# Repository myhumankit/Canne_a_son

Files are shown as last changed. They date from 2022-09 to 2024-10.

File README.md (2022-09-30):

# Canne_a_son

Prototype de canne blanche électronique pour détecter des obstacles. 

Ce projet est expliqué en détail sur le wikilab de My Human Kit : https://wikilab.myhumankit.org/index.php?title=Projets:Canne_a_son_V2

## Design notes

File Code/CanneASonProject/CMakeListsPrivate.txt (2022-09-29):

# !!! WARNING !!! AUTO-GENERATED FILE, PLEASE DO NOT MODIFY IT AND USE
# https://docs.platformio.org/page/projectconf/section_env_build.html#build-flags
#
# If you need to override existing CMake configuration or add extra,
# please create `CMakeListsUser.txt` in the root of project.
# The `CMakeListsUser.txt` will not be overwritten by PlatformIO.

set(CMAKE_CONFIGURATION_TYPES "m5stack-atom" CACHE STRING "Build Types reflect PlatformIO Environments" FORCE)

# Convert "Home Directory" that may contain unescaped backslashes on Windows
file(TO_CMAKE_PATH $ENV{HOMEDRIVE}$ENV{HOMEPATH} ENV_HOME_PATH)

SET(CMAKE_C_COMPILER "${ENV_HOME_PATH}/.platformio/packages/toolchain-xtensa-esp32/bin/xtensa-esp32-elf-gcc.exe")
SET(CMAKE_CXX_COMPILER "${ENV_HOME_PATH}/.platformio/packages/toolchain-xtensa-esp32/bin/xtensa-esp32-elf-g++.exe")
SET(CMAKE_CXX_FLAGS "-mlongcalls -Wno-frame-address -std=gnu++11 -fexceptions -fno-rtti -ffunction-sections -fdata-sections -Wno-error=unused-function -Wno-error=unused-variable -Wno-error=deprecated-declarations -Wno-unused-parameter -Wno-sign-compare -ggdb -Os -freorder-blocks -Wwrite-strings -fstack-protector -fstrict-volatile-bitfields -Wno-error=unused-but-set-variable -fno-jump-tables -fno-tree-switch-conversion -MMD")
SET(CMAKE_C_FLAGS "-mlongcalls -Wno-frame-address -std=gnu99 -Wno-old-style-declaration -ffunction-sections -fdata-sections -Wno-error=unused-function -Wno-error=unused-variable -Wno-error=deprecated-declarations -Wno-unused-parameter -Wno-sign-compare -ggdb -Os -freorder-blocks -Wwrite-strings -fstack-protector -fstrict-volatile-bitfields -Wno-error=unused-but-set-variable -fno-jump-tables -fno-tree-switch-conversion -MMD")

SET(CMAKE_C_STANDARD 99)
set(CMAKE_CXX_STANDARD 11)

if (CMAKE_BUILD_TYPE MATCHES "m5stack-atom")
    add_definitions(-DPLATFORMIO=60002)
    add_definitions(-DARDUINO_M5Stack_ATOM)
    add_definitions(-DHAVE_CONFIG_H)
    add_definitions(-DMBEDTLS_CONFIG_FILE=\"mbedtls/esp_config.h\")
    add_definitions(-DUNITY_INCLUDE_CONFIG_H)
    add_definitions(-DWITH_POSIX)
    add_definitions(-D_GNU_SOURCE)
    add_definitions(-DIDF_VER=\"v4.4.1-1-gb8050b365e\")
    add_definitions(-DESP_PLATFORM)
    add_definitions(-D_POSIX_READER_WRITER_LOCKS)
    add_definitions(-DARDUINO_ARCH_ESP32)
    add_definitions(-DESP32)
    add_definitions(-DF_CPU=240000000L)
    add_definitions(-DARDUINO=10812)
    add_definitions(-DARDUINO_VARIANT=\"m5stack_atom\")
    add_definitions(-DARDUINO_BOARD=\"M5Stack-ATOM\")
    add_definitions(-DARDUINO_PARTITION_default)

    include_directories("${CMAKE_CURRENT_LIST_DIR}/include")
    include_directories("${CMAKE_CURRENT_LIST_DIR}/src")
    include_directories("${CMAKE_CURRENT_LIST_DIR}/lib/SmartsonicCH201/src")
    include_directories("${CMAKE_CURRENT_LIST_DIR}/.pio/libdeps/m5stack-atom/TFMPI2C/src")
    include_directories("${CMAKE_CURRENT_LIST_DIR}/.pio/libdeps/m5stack-atom/M5Atom/src")
    include_directories("${ENV_HOME_PATH}/.platformio/packages/framework-arduinoespressif32/libraries/Wire/src")
    include_directories("${CMAKE_CURRENT_LIST_DIR}/.pio/libdeps/m5stack-atom/FastLED/src")
    include_directories("${ENV_HOME_PATH}/.platformio/packages/framework-arduinoespressif32/libraries/SPI/src")
    include_directories("${ENV_HOME_PATH}/.platformio/packages/framework-arduinoespressif32/tools/sdk/esp32/include/config")
    include_directories("${ENV_HOME_PATH}/.platformio/packages/framework-arduinoespressif32/tools/sdk/esp32/include/newlib/platform_include")
    include_directories("${ENV_HOME_PATH}/.platformio/packages/framework-arduinoespressif32/tools/sdk/esp32/include/freertos/include")
    include_directories("${ENV_HOME_PATH}/.platformio/packages/framework-arduinoespressif32/tools/sdk/esp32/include/freertos/include/esp_additions/freertos")
    include_directories("${ENV_HOME_PATH}/.platformio/packages/framework-arduinoespressif32/tools/sdk/esp32/include/freertos/port/xtensa/include")
    include_directories("${ENV_HOME_PATH}/.platformio/packages/framework-arduinoespressif32/tools/sdk/esp32/include/freertos/include/esp_additions")
    include_directories("${ENV_HOME_PATH}/.platformio/packages/framework-arduinoespressif32/tools/sdk/esp32/include/esp_hw_support/include")
    include_directories("${ENV_HOME_PATH}/.platformio/packages/framework-arduinoespressif32/tools/sdk/esp32/include/esp_hw_support/include/soc")
    include_directories("${ENV_HOME_PATH}/.platformio/packages/framework-arduinoespressif32/tools/sdk/esp32/include/esp_hw_support/include/soc/esp32")
    include_directories("${ENV_HOME_PATH}/.platformio/packages/framework-arduinoespressif32/tools/sdk/esp32/include/esp_hw_support/port/esp32")
    include_directories("${ENV_HOME_PATH}/.platformio/packages/framework-arduinoespressif32/tools/sdk/esp32/include/esp_hw_support/port/esp32/private_include")
    include_directories("${ENV_HOME_PATH}/.platformio/packages/framework-arduinoespressif32/tools/sdk/esp32/include/heap/include")
    include_directories("${ENV_HOME_PATH}/.platformio/packages/framework-arduinoespressif32/tools/sdk/esp32/include/log/include")
    include_directories("${ENV_HOME_PATH}/.platformio/packages/framework-arduinoespressif32/tools/sdk/esp32/include/lwip/include/apps")
    include_directories("${ENV_HOME_PATH}/.platformio/packages/framework-arduinoespressif32/tools/sdk/esp32/include/lwip/include/apps/sntp")
    include_directories("${ENV_HOME_PATH}/.platformio/packages/framework-arduinoespressif32/tools/sdk/esp32/include/lwip/lwip/src/include")
    include_directories("${ENV_HOME_PATH}/.platformio/packages/framework-arduinoespressif32/tools/sdk/esp32/include/lwip/port/esp32/include")
    include_directories("${ENV_HOME_PATH}/.platformio/packages/framework-arduinoespressif32/tools/sdk/esp32/include/lwip/port/esp32/include/arch")
    include_directories("${ENV_HOME_PATH}/.platformio/packages/framework-arduinoespressif32/tools/sdk/esp32/include/soc/include")
    include_directories("${ENV_HOME_PATH}/.platformio/packages/framework-arduinoespressif32/tools/sdk/esp32/include/soc/esp32")
    include_directories("${ENV_HOME_PATH}/.platformio/packages/framework-arduinoespressif32/tools/sdk/esp32/include/soc/esp32/include")
    include_directories("${ENV_HOME_PATH}/.platformio/packages/framework-arduinoespressif32/tools/sdk/esp32/include/hal/esp32/include")
    include_directories("${ENV_HOME_PATH}/.platformio/packages/framework-arduinoespressif32/tools/sdk/esp32/include/hal/include")
    include_directories("${ENV_HOME_PATH}/.platformio/packages/framework-arduinoespressif32/tools/sdk/esp32/include/hal/platform_port/include")
    include_directories("${ENV_HOME_PATH}/.platformio/packages/framework-arduinoespressif32/tools/sdk/esp32/include/esp_rom/include")
    include_directories("${ENV_HOME_PATH}/.platformio/packages/framework-arduinoespressif32/tools/sdk/esp32/include/esp_rom/include/esp32")
    include_directories("${ENV_HOME_PATH}/.platformio/packages/framework-arduinoespressif32/tools/sdk/esp32/include/esp_rom/esp32")
    include_directories("${ENV_HOME_PATH}/.platformio/packages/framework-arduinoespressif32/tools/sdk/esp32/include/esp_common/include")
    include_directories("${ENV_HOME_PATH}/.platformio/packages/framework-arduinoespressif32/tools/sdk/esp32/include/esp_system/include")
    include_directories("${ENV_HOME_PATH}/.platformio/packages/framework-arduinoespressif32/tools/sdk/esp32/include/esp_system/port/soc")
    include_directories("${ENV_HOME_PATH}/.platformio/packages/framework-arduinoespressif32/tools/sdk/esp32/include/esp_system/port/public_compat")
    include_directories("${ENV_HOME_PATH}/.platformio/packages/framework-arduinoespressif32/tools/sdk/esp32/include/esp32/include")
    include_directories("${ENV_HOME_PATH}/.platformio/packages/framework-arduinoespressif32/tools/sdk/esp32/include/xtensa/include")
    include_directories("${ENV_HOME_PATH}/.platformio/packages/framework-arduinoespressif32/tools/sdk/esp32/include/xtensa/esp32/include")
    include_directories("${ENV_HOME_PATH}/.platformio/packages/framework-arduinoespressif32/tools/sdk/esp32/include/driver/include")
    include_directories("${ENV_HOME_PATH}/.platformio/packages/framework-arduinoespressif32/tools/sdk/esp32/include/driver/esp32/include")
    include_directories("${ENV_HOME_PATH}/.platformio/packages/framework-arduinoespressif32/tools/sdk/esp32/include/esp_pm/include")
    include_directories("${ENV_HOME_PATH}/.platformio/packages/framework-arduinoespressif32/tools/sdk/esp32/include/esp_ringbuf/include")
    include_directories("${ENV_HOME_PATH}/.platformio/packages/framework-arduinoespressif32/tools/sdk/esp32/include/efuse/include")
    include_directories("${ENV_HOME_PATH}/.platformio/packages/framework-arduinoespressif32/tools/sdk/esp32/include/efuse/esp32/include")
    include_directories("${ENV_HOME_PATH}/.platformio/packages/framework-arduinoespressif32/tools/sdk/esp32/include/vfs/include")
    include_directories("${ENV_HOME_PATH}/.platformio/packages/framework-arduinoespressif32/tools/sdk/esp32/include/esp_wifi/include")
    include_directories("${ENV_HOME_PATH}/.platformio/packages/framework-arduinoespressif32/tools/sdk/esp32/include/esp_event/include")
    include_directories("${ENV_HOME_PATH}/.platformio/packages/framework-arduinoespressif32/tools/sdk/esp32/include/esp_netif/include")
    include_directories("${ENV_HOME_PATH}/.platformio/packages/framework-arduinoespressif32/tools/sdk/esp32/include/esp_eth/include")
    include_directories("${ENV_HOME_PATH}/.platformio/packages/framework-arduinoespressif32/tools/sdk/esp32/include/tcpip_adapter/include")
    include_directories("${ENV_HOME_PATH}/.platformio/packages/framework-arduinoespressif32/tools/sdk/esp32/include/esp_phy/include")
    include_directories("${ENV_HOME_PATH}/.platformio/packages/framework-arduinoespressif32/tools/sdk/esp32/include/esp_phy/esp32/include")
    include_directories("${ENV_HOME_PATH}/.platformio/packages/framework-arduinoespressif32/tools/sdk/esp32/include/esp_ipc/include")
    include_directories("${ENV_HOME_PATH}/.platformio/packages/framework-arduinoespressif32/tools/sdk/esp32/include/app_trace/include")
    include_directories("${ENV_HOME_PATH}/.platformio/packages/framework-arduinoespressif32/tools/sdk/esp32/include/esp_timer/include")
    include_directories("${ENV_HOME_PATH}/.platformio/packages/framework-arduinoespressif32/tools/sdk/esp32/include/mbedtls/port/include")
    include_directories("${ENV_HOME_PATH}/.platformio/packages/framework-arduinoespressif32/tools/sdk/esp32/include/mbedtls/mbedtls/include")
    include_directories("${ENV_HOME_PATH}/.platformio/packages/framework-arduinoespressif32/tools/sdk/esp32/include/mbedtls/esp_crt_bundle/include")
    include_directories("${ENV_HOME_PATH}/.platformio/packages/framework-arduinoespressif32/tools/sdk/esp32/include/app_update/include")
    include_directories("${ENV_HOME_PATH}/.platformio/packages/framework-arduinoespressif32/tools/sdk/esp32/include/spi_flash/include")
    include_directories("${ENV_HOME_PATH}/.platformio/packages/framework-arduinoespressif32/tools/sdk/esp32/include/bootloader_support/include")
    include_directories("${ENV_HOME_PATH}/.platformio/packages/framework-arduinoespressif32/tools/sdk/esp32/include/nvs_flash/include")
    include_directories("${ENV_HOME_PATH}/.platformio/packages/framework-arduinoespressif32/tools/sdk/esp32/include/pthread/include")
    include_directories("${ENV_HOME_PATH}/.platformio/packages/framework-arduinoespressif32/tools/sdk/esp32/include/esp_gdbstub/include")
    include_directories("${ENV_HOME_PATH}/.platformio/packages/framework-arduinoespressif32/tools/sdk/esp32/include/esp_gdbstub/xtensa")
    include_directories("${ENV_HOME_PATH}/.platformio/packages/framework-arduinoespressif32/tools/sdk/esp32/include/esp_gdbstub/esp32")
    include_directories("${ENV_HOME_PATH}/.platformio/packages/framework-arduinoespressif32/tools/sdk/esp32/include/espcoredump/include")
    include_directories("${ENV_HOME_PATH}/.platformio/packages/framework-arduinoespressif32/tools/sdk/esp32/include/espcoredump/include/port/xtensa")
    include_directories("${ENV_HOME_PATH}/.platformio/packages/framework-arduinoespressif32/tools/sdk/esp32/include/wpa_supplicant/include")
    include_directories("${ENV_HOME_PATH}/.platformio/packages/framework-arduinoespressif32/tools/sdk/esp32/include/wpa_supplicant/port/include")
    include_directories("${ENV_HOME_PATH}/.platformio/packages/framework-arduinoespressif32/tools/sdk/esp32/include/wpa_supplicant/esp_supplicant/include")
    include_directories("${ENV_HOME_PATH}/.platformio/packages/framework-arduinoespressif32/tools/sdk/esp32/include/ieee802154/include")
    include_directories("${ENV_HOME_PATH}/.platformio/packages/framework-arduinoespressif32/tools/sdk/esp32/include/console")
    include_directories("${ENV_HOME_PATH}/.platformio/packages/framework-arduinoespressif32/tools/sdk/esp32/include/asio/asio/asio/include")
    include_directories("${ENV_HOME_PATH}/.platformio/packages/framework-arduinoespressif32/tools/sdk/esp32/include/asio/port/include")
    include_directories("${ENV_HOME_PATH}/.platformio/packages/framework-arduinoespressif32/tools/sdk/esp32/include/bt/common/osi/include")
    include_directories("${ENV_HOME_PATH}/.platformio/packages/framework-arduinoespressif32/tools/sdk/esp32/include/bt/include/esp32/include")
    include_directories("${ENV_HOME_PATH}/.platformio/packages/framework-arduinoespressif32/tools/sdk/esp32/include/bt/common/api/include/api")
    include_directories("${ENV_HOME_PATH}/.platformio/packages/framework-arduinoespressif32/tools/sdk/esp32/include/bt/common/btc/profile/esp/blufi/include")
    include_directories("${ENV_HOME_PATH}/.platformio/packages/framework-arduinoespressif32/tools/sdk/esp32/include/bt/common/btc/profile/esp/include")
    include_directories("${ENV_HOME_PATH}/.platformio/packages/framework-arduinoespressif32/tools/sdk/esp32/include/bt/host/bluedroid/api/include/api")
    include_directories("${ENV_HOME_PATH}/.platformio/packages/framework-arduinoespressif32/tools/sdk/esp32/include/cbor/port/include")
    include_directories("${ENV_HOME_PATH}/.platformio/packages/framework-arduinoespressif32/tools/sdk/esp32/include/unity/include")
    include_directories("${ENV_HOME_PATH}/.platformio/packages/framework-arduinoespressif32/tools/sdk/esp32/include/unity/unity/src")
    include_directories("${ENV_HOME_PATH}/.platformio/packages/framework-arduinoespressif32/tools/sdk/esp32/include/cmock/CMock/src")
    include_directories("${ENV_HOME_PATH}/.platformio/packages/framework-arduinoespressif32/tools/sdk/esp32/include/coap/port/include")
    include_directories("${ENV_HOME_PATH}/.platformio/packages/framework-arduinoespressif32/tools/sdk/esp32/include/coap/libcoap/include")
    include_directories("${ENV_HOME_PATH}/.platformio/packages/framework-arduinoespressif32/tools/sdk/esp32/include/nghttp/port/include")
    include_directories("${ENV_HOME_PATH}/.platformio/packages/framework-arduinoespressif32/tools/sdk/esp32/include/nghttp/nghttp2/lib/includes")
    include_directories("${ENV_HOME_PATH}/.platformio/packages/framework-arduinoespressif32/tools/sdk/esp32/include/esp-tls")
    include_directories("${ENV_HOME_PATH}/.platformio/packages/framework-arduinoespressif32/tools/sdk/esp32/include/esp-tls/esp-tls-crypto")
    include_directories("${ENV_HOME_PATH}/.platformio/packages/framework-arduinoespressif32/tools/sdk/esp32/include/esp_adc_cal/include")
    include_directories("${ENV_HOME_PATH}/.platformio/packages/framework-arduinoespressif32/tools/sdk/esp32/include/esp_hid/include")
    include_directories("${ENV_HOME_PATH}/.platformio/packages/framework-arduinoespressif32/tools/sdk/esp32/include/tcp_transport/include")
    include_directories("${ENV_HOME_PATH}/.platformio/packages/framework-arduinoespressif32/tools/sdk/esp32/include/esp_http_client/include")
    include_directories("${ENV_HOME_PATH}/.platformio/packages/framework-arduinoespressif32/tools/sdk/esp32/include/esp_http_server/include")
    include_directories("${ENV_HOME_PATH}/.platformio/packages/framework-arduinoespressif32/tools/sdk/esp32/include/esp_https_ota/include")
    include_directories("${ENV_HOME_PATH}/.platformio/packages/framework-arduinoespressif32/tools/sdk/esp32/include/esp_lcd/include")
    include_directories("${ENV_HOME_PATH}/.platformio/packages/framework-arduinoespressif32/tools/sdk/esp32/include/esp_lcd/interface")
    include_directories("${ENV_HOME_PATH}/.platformio/packages/framework-arduinoespressif32/tools/sdk/esp32/include/protobuf-c/protobuf-c")
    include_directories("${ENV_HOME_PATH}/.platformio/packages/framework-arduinoespressif32/tools/sdk/esp32/include/protocomm/include/common")
    include_directories("${ENV_HOME_PATH}/.platformio/packages/framework-arduinoespressif32/tools/sdk/esp32/include/protocomm/include/security")
    include_directories("${ENV_HOME_PATH}/.platformio/packages/framework-arduinoespressif32/tools/sdk/esp32/include/protocomm/include/transports")
    include_directories("${ENV_HOME_PATH}/.platformio/packages/framework-arduinoespressif32/tools/sdk/esp32/include/mdns/include")
    include_directories("${ENV_HOME_PATH}/.platformio/packages/framework-arduinoespressif32/tools/sdk/esp32/include/esp_local_ctrl/include")
    include_directories("${ENV_HOME_PATH}/.platformio/packages/framework-arduinoespressif32/tools/sdk/esp32/include/sdmmc/include")
    include_directories("${ENV_HOME_PATH}/.platformio/packages/framework-arduinoespressif32/tools/sdk/esp32/include/esp_serial_slave_link/include")
    include_directories("${ENV_HOME_PATH}/.platformio/packages/framework-arduinoespressif32/tools/sdk/esp32/include/esp_websocket_client/include")
    include_directories("${ENV_HOME_PATH}/.platformio/packages/framework-arduinoespressif32/tools/sdk/esp32/include/expat/expat/expat/lib")
    include_directories("${ENV_HOME_PATH}/.platformio/packages/framework-arduinoespressif32/tools/sdk/esp32/include/expat/port/include")
    include_directories("${ENV_HOME_PATH}/.platformio/packages/framework-arduinoespressif32/tools/sdk/esp32/include/wear_levelling/include")
    include_directories("${ENV_HOME_PATH}/.platformio/packages/framework-arduinoespressif32/tools/sdk/esp32/include/fatfs/diskio")
    include_directories("${ENV_HOME_PATH}/.platformio/packages/framework-arduinoespressif32/tools/sdk/esp32/include/fatfs/vfs")
    include_directories("${ENV_HOME_PATH}/.platformio/packages/framework-arduinoespressif32/tools/sdk/esp32/include/fatfs/src")
    include_directories("${ENV_HOME_PATH}/.platformio/packages/framework-arduinoespressif32/tools/sdk/esp32/include/freemodbus/common/include")
    include_directories("${ENV_HOME_PATH}/.platformio/packages/framework-arduinoespressif32/tools/sdk/esp32/include/idf_test/include")
    include_directories("${ENV_HOME_PATH}/.platformio/packages/framework-arduinoespressif32/tools/sdk/esp32/include/idf_test/include/esp32")
    include_directories("${ENV_HOME_PATH}/.platformio/packages/framework-arduinoespressif32/tools/sdk/esp32/include/jsmn/include")
    include_directories("${ENV_HOME_PATH}/.platformio/packages/framework-arduinoespressif32/tools/sdk/esp32/include/json/cJSON")
    include_directories("${ENV_HOME_PATH}/.platformio/packages/framework-arduinoespressif32/tools/sdk/esp32/include/libsodium/libsodium/src/libsodium/include")
    include_directories("${ENV_HOME_PATH}/.platformio/packages/framework-arduinoespressif32/tools/sdk/esp32/include/libsodium/port_include")
    include_directories("${ENV_HOME_PATH}/.platformio/packages/framework-arduinoespressif32/tools/sdk/esp32/include/mqtt/esp-mqtt/include")
    include_directories("${ENV_HOME_PATH}/.platformio/packages/framework-arduinoespressif32/tools/sdk/esp32/include/openssl/include")
    include_directories("${ENV_HOME_PATH}/.platformio/packages/framework-arduinoespressif32/tools/sdk/esp32/include/perfmon/include")
    include_directories("${ENV_HOME_PATH}/.platformio/packages/framework-arduinoespressif32/tools/sdk/esp32/include/spiffs/include")
    include_directories("${ENV_HOME_PATH}/.platformio/packages/framework-arduinoespressif32/tools/sdk/esp32/include/ulp/include")
    include_directories("${ENV_HOME_PATH}/.platformio/packages/framework-arduinoespressif32/tools/sdk/esp32/include/wifi_provisioning/include")
    include_directories("${ENV_HOME_PATH}/.platformio/packages/framework-arduinoespressif32/tools/sdk/esp32/include/button/button/include")
    include_directories("${ENV_HOME_PATH}/.platformio/packages/framework-arduinoespressif32/tools/sdk/esp32/include/rmaker_common/include")
    include_directories("${ENV_HOME_PATH}/.platformio/packages/framework-arduinoespressif32/tools/sdk/esp32/include/json_parser/upstream/include")
    include_directories("${ENV_HOME_PATH}/.platformio/packages/framework-arduinoespressif32/tools/sdk/esp32/include/json_parser/upstream")
    include_directories("${ENV_HOME_PATH}/.platformio/packages/framework-arduinoespressif32/tools/sdk/esp32/include/json_generator/upstream")
    include_directories("${ENV_HOME_PATH}/.platformio/packages/framework-arduinoespressif32/tools/sdk/esp32/include/esp_schedule/include")
    include_directories("${ENV_HOME_PATH}/.platformio/packages/framework-arduinoespressif32/tools/sdk/esp32/include/esp_rainmaker/include")
    include_directories("${ENV_HOME_PATH}/.platformio/packages/framework-arduinoespressif32/tools/sdk/esp32/include/qrcode/include")
    include_directories("${ENV_HOME_PATH}/.platformio/packages/framework-arduinoespressif32/tools/sdk/esp32/include/ws2812_led")
    include_directories("${ENV_HOME_PATH}/.platformio/packages/framework-arduinoespressif32/tools/sdk/esp32/include/esp-dsp/modules/dotprod/include")
    include_directories("${ENV_HOME_PATH}/.platformio/packages/framework-arduinoespressif32/tools/sdk/esp32/include/esp-dsp/modules/support/include")
    include_directories("${ENV_HOME_PATH}/.platformio/packages/framework-arduinoespressif32/tools/sdk/esp32/include/esp-dsp/modules/windows/include")
    include_directories("${ENV_HOME_PATH}/.platformio/packages/framework-arduinoespressif32/tools/sdk/esp32/include/esp-dsp/modules/windows/hann/include")
    include_directories("${ENV_HOME_PATH}/.platformio/packages/framework-arduinoespressif32/tools/sdk/esp32/include/esp-dsp/modules/windows/blackman/include")
    include_directories("${ENV_HOME_PATH}/.platformio/packages/framework-arduinoespressif32/tools/sdk/esp32/include/esp-dsp/modules/windows/blackman_harris/include")
    include_directories("${ENV_HOME_PATH}/.platformio/packages/framework-arduinoespressif32/tools/sdk/esp32/include/esp-dsp/modules/windows/blackman_nuttall/include")
    include_directories("${ENV_HOME_PATH}/.platformio/packages/framework-arduinoespressif32/tools/sdk/esp32/include/esp-dsp/modules/windows/nuttall/include")
    include_directories("${ENV_HOME_PATH}/.platformio/packages/framework-arduinoespressif32/tools/sdk/esp32/include/esp-dsp/modules/windows/flat_top/include")
    include_directories("${ENV_HOME_PATH}/.platformio/packages/framework-arduinoespressif32/tools/sdk/esp32/include/esp-dsp/modules/iir/include")
    include_directories("${ENV_HOME_PATH}/.platformio/packages/framework-arduinoespressif32/tools/sdk/esp32/include/esp-dsp/modules/fir/include")
    include_directories("${ENV_HOME_PATH}/.platformio/packages/framework-arduinoespressif32/tools/sdk/esp32/include/esp-dsp/modules/math/include")
    include_directories("${ENV_HOME_PATH}/.platformio/packages/framework-arduinoespressif32/tools/sdk/esp32/include/esp-dsp/modules/math/add/include")
    include_directories("${ENV_HOME_PATH}/.platformio/packages/framework-arduinoespressif32/tools/sdk/esp32/include/esp-dsp/modules/math/sub/include")
    include_directories("${ENV_HOME_PATH}/.platformio/packages/framework-arduinoespressif32/tools/sdk/esp32/include/esp-dsp/modules/math/mul/include")
    include_directories("${ENV_HOME_PATH}/.platformio/packages/framework-arduinoespressif32/tools/sdk/esp32/include/esp-dsp/modules/math/addc/include")
    include_directories("${ENV_HOME_PATH}/.platformio/packages/framework-arduinoespressif32/tools/sdk/esp32/include/esp-dsp/modules/math/mulc/include")
    include_directories("${ENV_HOME_PATH}/.platformio/packages/framework-arduinoespressif32/tools/sdk/esp32/include/esp-dsp/modules/math/sqrt/include")
    include_directories("${ENV_HOME_PATH}/.platformio/packages/framework-arduinoespressif32/tools/sdk/esp32/include/esp-dsp/modules/matrix/include")
    include_directories("${ENV_HOME_PATH}/.platformio/packages/framework-arduinoespressif32/tools/sdk/esp32/include/esp-dsp/modules/fft/include")
    include_directories("${ENV_HOME_PATH}/.platformio/packages/framework-arduinoespressif32/tools/sdk/esp32/include/esp-dsp/modules/dct/include")
    include_directories("${ENV_HOME_PATH}/.platformio/packages/framework-arduinoespressif32/tools/sdk/esp32/include/esp-dsp/modules/conv/include")
    include_directories("${ENV_HOME_PATH}/.platformio/packages/framework-arduinoespressif32/tools/sdk/esp32/include/esp-dsp/modules/common/include")
    include_directories("${ENV_HOME_PATH}/.platformio/packages/framework-arduinoespressif32/tools/sdk/esp32/include/esp-dsp/modules/kalman/ekf/include")
    include_directories("${ENV_HOME_PATH}/.platformio/packages/framework-arduinoespressif32/tools/sdk/esp32/include/esp-dsp/modules/kalman/ekf_imu13states/include")
    include_directories("${ENV_HOME_PATH}/.platformio/packages/framework-arduinoespressif32/tools/sdk/esp32/include/esp_littlefs/src")
    include_directories("${ENV_HOME_PATH}/.platformio/packages/framework-arduinoespressif32/tools/sdk/esp32/include/esp_littlefs/include")
    include_directories("${ENV_HOME_PATH}/.platformio/packages/framework-arduinoespressif32/tools/sdk/esp32/include/esp-dl/include")
    include_directories("${ENV_HOME_PATH}/.platformio/packages/framework-arduinoespressif32/tools/sdk/esp32/include/esp-dl/include/tool")
    include_directories("${ENV_HOME_PATH}/.platformio/packages/framework-arduinoespressif32/tools/sdk/esp32/include/esp-dl/include/typedef")
    include_directories("${ENV_HOME_PATH}/.platformio/packages/framework-arduinoespressif32/tools/sdk/esp32/include/esp-dl/include/image")
    include_directories("${ENV_HOME_PATH}/.platformio/packages/framework-arduinoespressif32/tools/sdk/esp32/include/esp-dl/include/math")
    include_directories("${ENV_HOME_PATH}/.platformio/packages/framework-arduinoespressif32/tools/sdk/esp32/include/esp-dl/include/nn")
    include_directories("${ENV_HOME_PATH}/.platformio/packages/framework-arduinoespressif32/tools/sdk/esp32/include/esp-dl/include/layer")
    include_directories("${ENV_HOME_PATH}/.platformio/packages/framework-arduinoespressif32/tools/sdk/esp32/include/esp-dl/include/detect")
    include_directories("${ENV_HOME_PATH}/.platformio/packages/framework-arduinoespressif32/tools/sdk/esp32/include/esp-dl/include/model_zoo")
    include_directories("${ENV_HOME_PATH}/.platformio/packages/framework-arduinoespressif32/tools/sdk/esp32/include/esp-sr/esp-tts/esp_tts_chinese/include")
    include_directories("${ENV_HOME_PATH}/.platformio/packages/framework-arduinoespressif32/tools/sdk/esp32/include/esp-sr/include/esp32")
    include_directories("${ENV_HOME_PATH}/.platformio/packages/framework-arduinoespressif32/tools/sdk/esp32/include/esp32-camera/driver/include")
    include_directories("${ENV_HOME_PATH}/.platformio/packages/framework-arduinoespressif32/tools/sdk/esp32/include/esp32-camera/conversions/include")
    include_directories("${ENV_HOME_PATH}/.platformio/packages/framework-arduinoespressif32/tools/sdk/esp32/include/fb_gfx/include")
    include_directories("${ENV_HOME_PATH}/.platformio/packages/framework-arduinoespressif32/tools/sdk/esp32/qspi_qspi/include")
    include_directories("${ENV_HOME_PATH}/.platformio/packages/framework-arduinoespressif32/cores/esp32")
    include_directories("${ENV_HOME_PATH}/.platformio/packages/framework-arduinoespressif32/variants/m5stack_atom")
    include_directories("${ENV_HOME_PATH}/.platformio/packages/framework-arduinoespressif32/libraries/ArduinoOTA/src")
    include_directories("${ENV_HOME_PATH}/.platformio/packages/framework-arduinoespressif32/libraries/AsyncUDP/src")
    include_directories("${ENV_HOME_PATH}/.platformio/packages/framework-arduinoespressif32/libraries/BLE/src")
    include_directories("${ENV_HOME_PATH}/.platformio/packages/framework-arduinoespressif32/libraries/BluetoothSerial/src")
    include_directories("${ENV_HOME_PATH}/.platformio/packages/framework-arduinoespressif32/libraries/DNSServer/src")
    include_directories("${ENV_HOME_PATH}/.platformio/packages/framework-arduinoespressif32/libraries/EEPROM/src")
    include_directories("${ENV_HOME_PATH}/.platformio/packages/framework-arduinoespressif32/libraries/ESP32/src")
    include_directories("${ENV_HOME_PATH}/.platformio/packages/framework-arduinoespressif32/libraries/ESPmDNS/src")
    include_directories("${ENV_HOME_PATH}/.platformio/packages/framework-arduinoespressif32/libraries/Ethernet/src")
    include_directories("${ENV_HOME_PATH}/.platformio/packages/framework-arduinoespressif32/libraries/FFat/src")
    include_directories("${ENV_HOME_PATH}/.platformio/packages/framework-arduinoespressif32/libraries/FS/src")
    include_directories("${ENV_HOME_PATH}/.platformio/packages/framework-arduinoespressif32/libraries/HTTPClient/src")
    include_directories("${ENV_HOME_PATH}/.platformio/packages/framework-arduinoespressif32/libraries/HTTPUpdate/src")
    include_directories("${ENV_HOME_PATH}/.platformio/packages/framework-arduinoespressif32/libraries/HTTPUpdateServer/src")
    include_directories("${ENV_HOME_PATH}/.platformio/packages/framework-arduinoespressif32/libraries/I2S/src")
    include_directories("${ENV_HOME_PATH}/.platformio/packages/framework-arduinoespressif32/libraries/LittleFS/src")
    include_directories("${ENV_HOME_PATH}/.platformio/packages/framework-arduinoespressif32/libraries/NetBIOS/src")
    include_directories("${ENV_HOME_PATH}/.platformio/packages/framework-arduinoespressif32/libraries/Preferences/src")
    include_directories("${ENV_HOME_PATH}/.platformio/packages/framework-arduinoespressif32/libraries/RainMaker/src")
    include_directories("${ENV_HOME_PATH}/.platformio/packages/framework-arduinoespressif32/libraries/SD/src")
    include_directories("${ENV_HOME_PATH}/.platformio/packages/framework-arduinoespressif32/libraries/SD_MMC/src")
    include_directories("${ENV_HOME_PATH}/.platformio/packages/framework-arduinoespressif32/libraries/SPIFFS/src")
    include_directories("${ENV_HOME_PATH}/.platformio/packages/framework-arduinoespressif32/libraries/SimpleBLE/src")
    include_directories("${ENV_HOME_PATH}/.platformio/packages/framework-arduinoespressif32/libraries/Ticker/src")
    include_directories("${ENV_HOME_PATH}/.platformio/packages/framework-arduinoespressif32/libraries/USB/src")
    include_directories("${ENV_HOME_PATH}/.platformio/packages/framework-arduinoespressif32/libraries/Update/src")
    include_directories("${ENV_HOME_PATH}/.platformio/packages/framework-arduinoespressif32/libraries/WebServer/src")
    include_directories("${ENV_HOME_PATH}/.platformio/packages/framework-arduinoespressif32/libraries/WiFi/src")
    include_directories("${ENV_HOME_PATH}/.platformio/packages/framework-arduinoespressif32/libraries/WiFiClientSecure/src")
    include_directories("${ENV_HOME_PATH}/.platformio/packages/framework-arduinoespressif32/libraries/WiFiProv/src")
    include_directories("${ENV_HOME_PATH}/.platformio/packages/toolchain-xtensa-esp32/xtensa-esp32-elf/include/c++/8.4.0")
    include_directories("${ENV_HOME_PATH}/.platformio/packages/toolchain-xtensa-esp32/xtensa-esp32-elf/include/c++/8.4.0/xtensa-esp32-elf")
    include_directories("${ENV_HOME_PATH}/.platformio/packages/toolchain-xtensa-esp32/lib/gcc/xtensa-esp32-elf/8.4.0/include")
    include_directories("${ENV_HOME_PATH}/.platformio/packages/toolchain-xtensa-esp32/lib/gcc/xtensa-esp32-elf/8.4.0/include-fixed")
    include_directories("${ENV_HOME_PATH}/.platformio/packages/toolchain-xtensa-esp32/xtensa-esp32-elf/include")

    FILE(GLOB_RECURSE EXTRA_LIB_SOURCES
        ${CMAKE_CURRENT_LIST_DIR}/.pio/libdeps/m5stack-atom/*.*
    )
endif()

FILE(GLOB_RECURSE SRC_LIST
    ${CMAKE_CURRENT_LIST_DIR}/src/*.*
    ${CMAKE_CURRENT_LIST_DIR}/lib/*.*
    ${CMAKE_CURRENT_LIST_DIR}/test/*.*
)

list(APPEND SRC_LIST ${EXTRA_LIB_SOURCES})

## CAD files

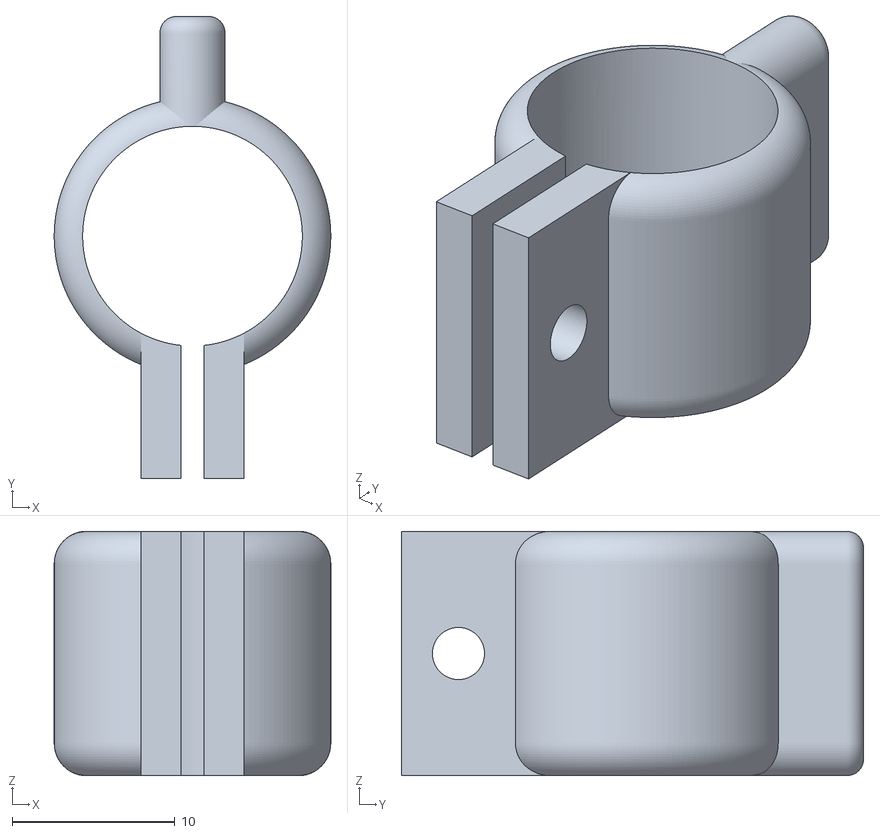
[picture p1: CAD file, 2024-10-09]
3DFiles/Blocage_Rotation_Canne/Blocage_Rotation_Part1.stl
17.0 x 28.4 x 15.0

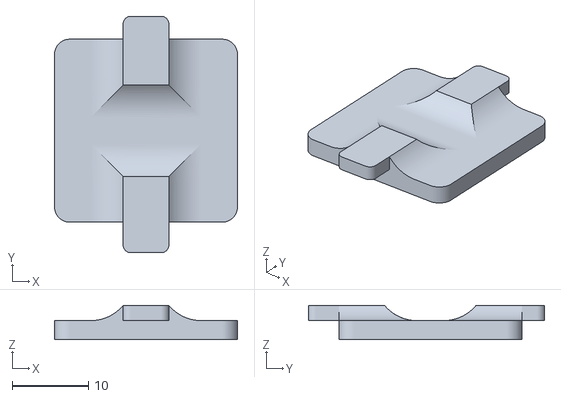
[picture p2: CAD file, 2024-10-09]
3DFiles/Boitier_CanneASon/AdaptateurBoitier_V2.0_to_V2.1.stl
24.0 x 31.0 x 4.50

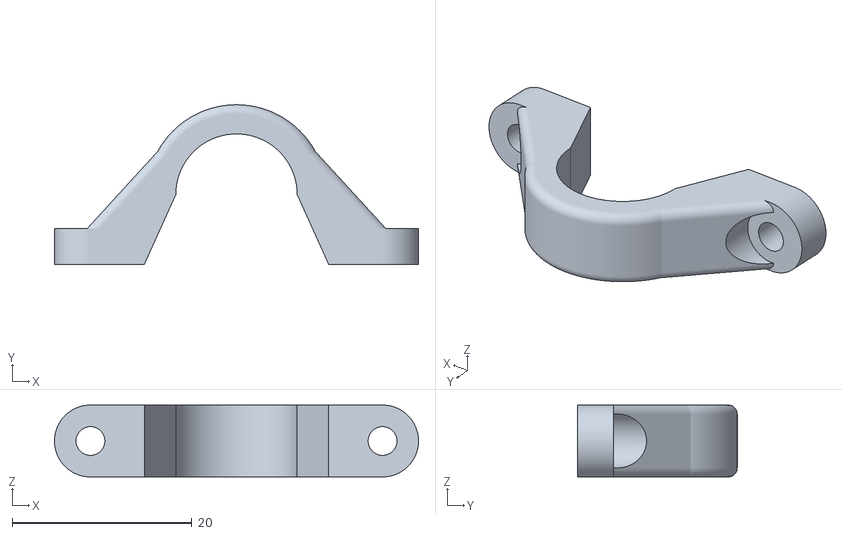
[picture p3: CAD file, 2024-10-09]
3DFiles/Support_Moteur_Vibrant/Support_Moteur_Vibrant_Part2.stl
40.5 x 17.7 x 8.00

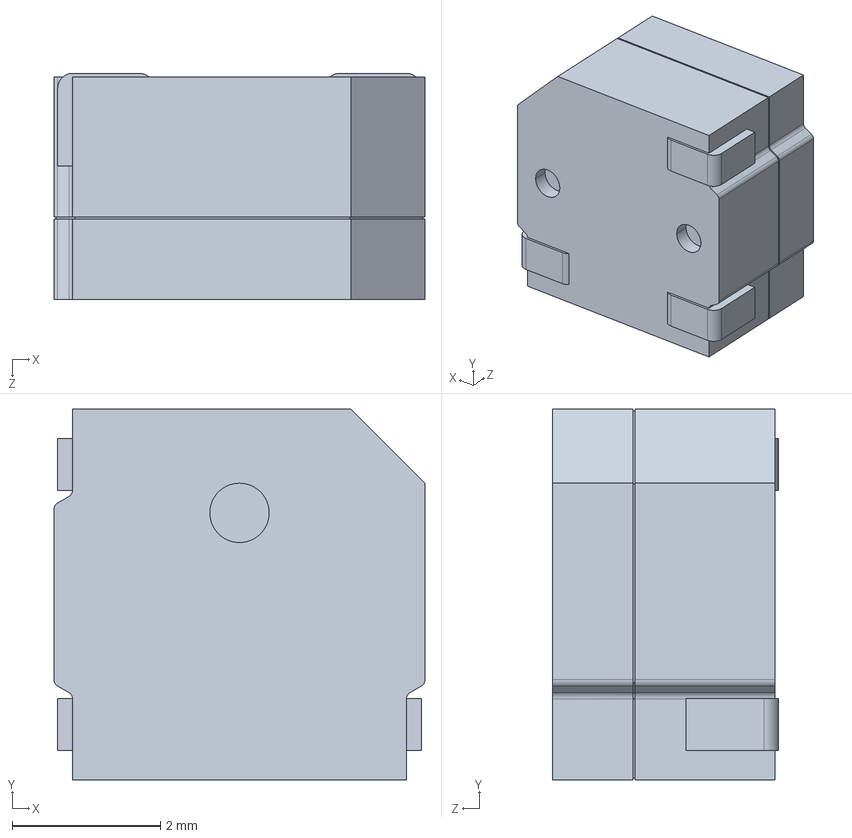
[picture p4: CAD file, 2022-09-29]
PCB/LibComponent/3Dmodel/KSSG13J12-N.STEP
5.00 x 5.00 x 3.05 mm

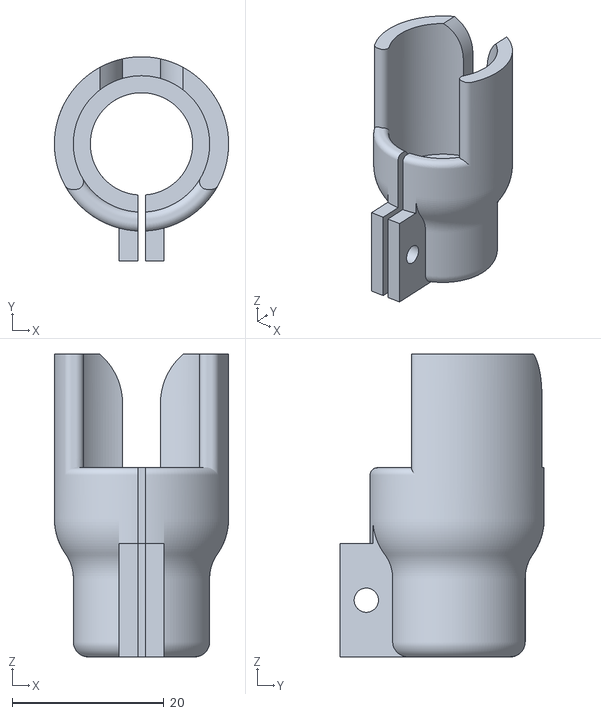
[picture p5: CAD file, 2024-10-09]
3DFiles/Blocage_Rotation_Canne/Blocage_Rotation_Part2.stl
23.0 x 27.0 x 40.0

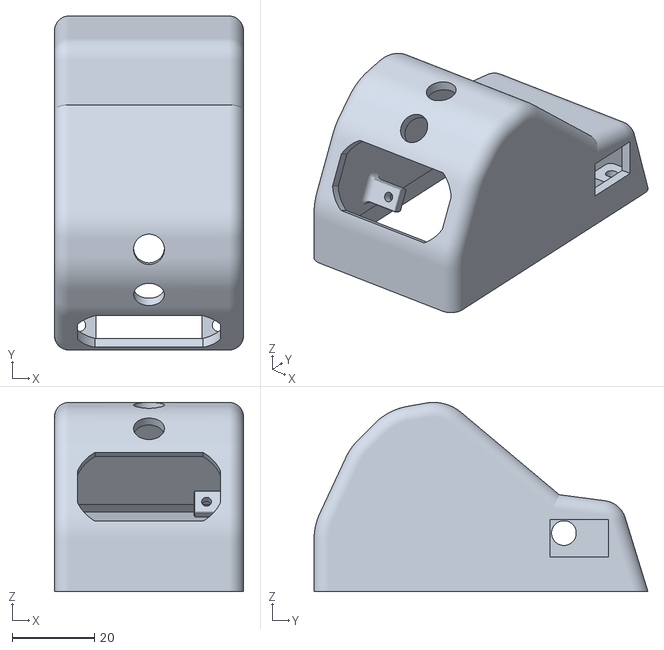
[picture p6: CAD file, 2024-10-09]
3DFiles/Boitier_CanneASon/CanneASon_Part1.stl
46.0 x 81.2 x 46.0

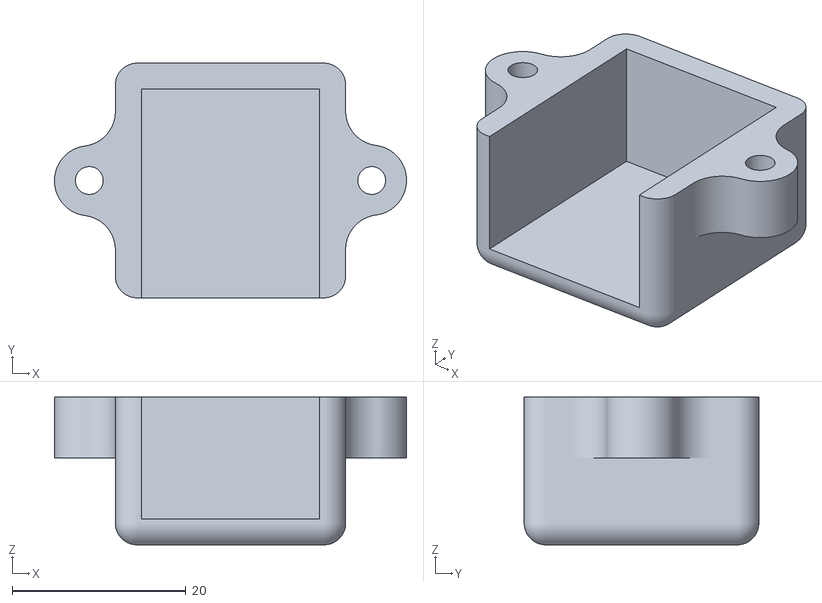
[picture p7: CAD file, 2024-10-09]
3DFiles/Support_Moteur_Vibrant/Support_Moteur_Vibrant_Part1.stl
40.5 x 27.0 x 17.0

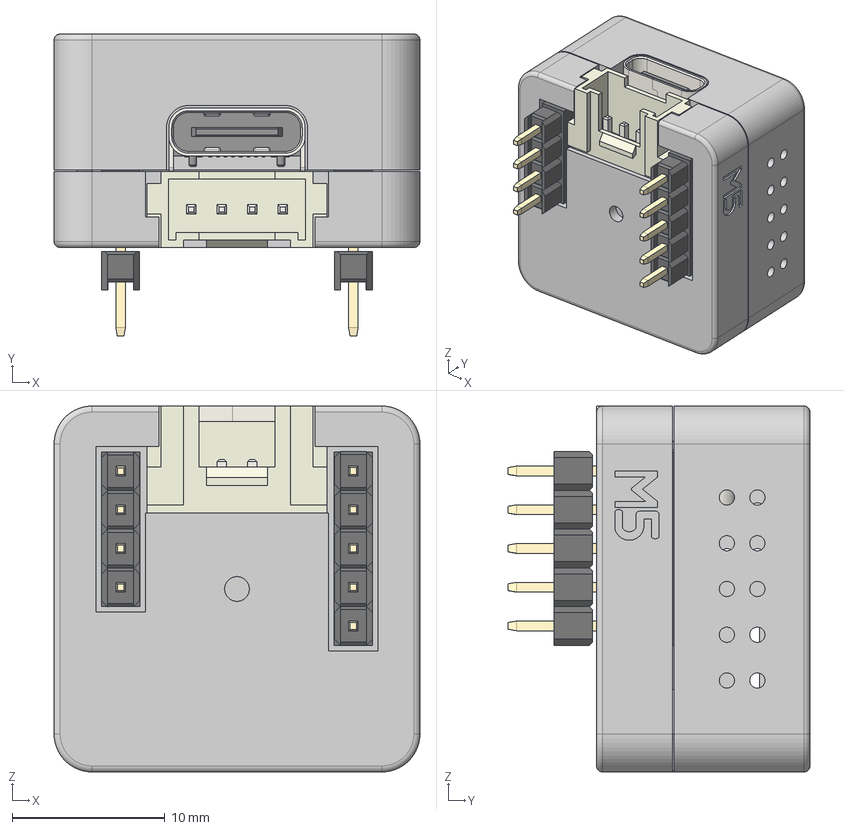
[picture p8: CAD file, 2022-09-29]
PCB/LibComponent/3Dmodel/M5Atom.step
24.0 x 19.8 x 24.0 mm
Grove socket
pinsocket_5 v2
pinsocket_4 v3
ConPins
PcbPins
Mold
Frame
1x4 Male Pin Header
1x5 Male Pin Header

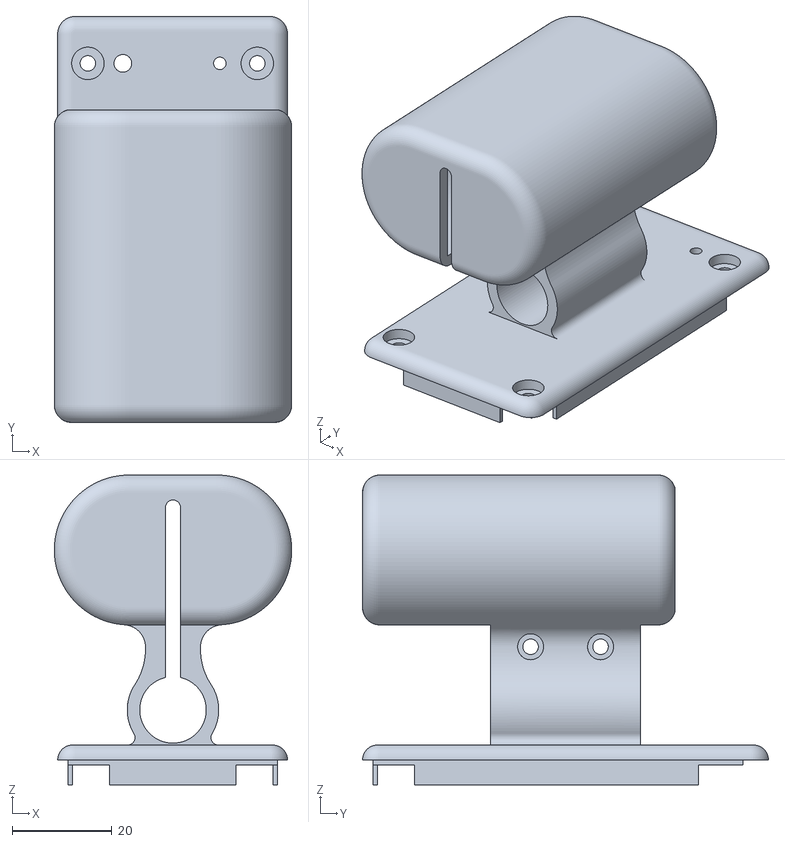
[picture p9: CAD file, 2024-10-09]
3DFiles/Boitier_CanneASon/CanneASon_Part2.stl
47.5 x 81.2 x 62.0

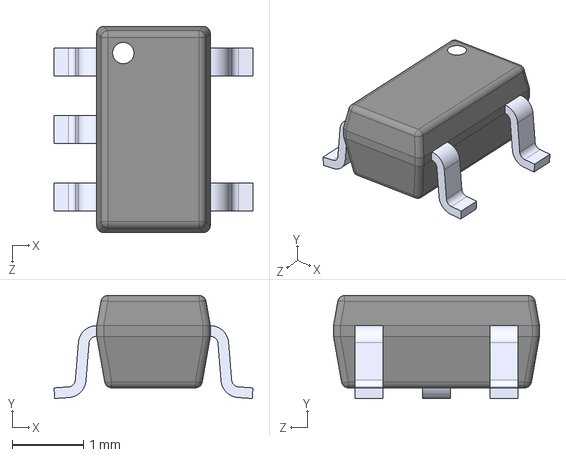
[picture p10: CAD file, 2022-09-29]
PCB/LibComponent/3Dmodel/LP2985A-18DBVR.STEP
2.80 x 1.45 x 2.90 mm

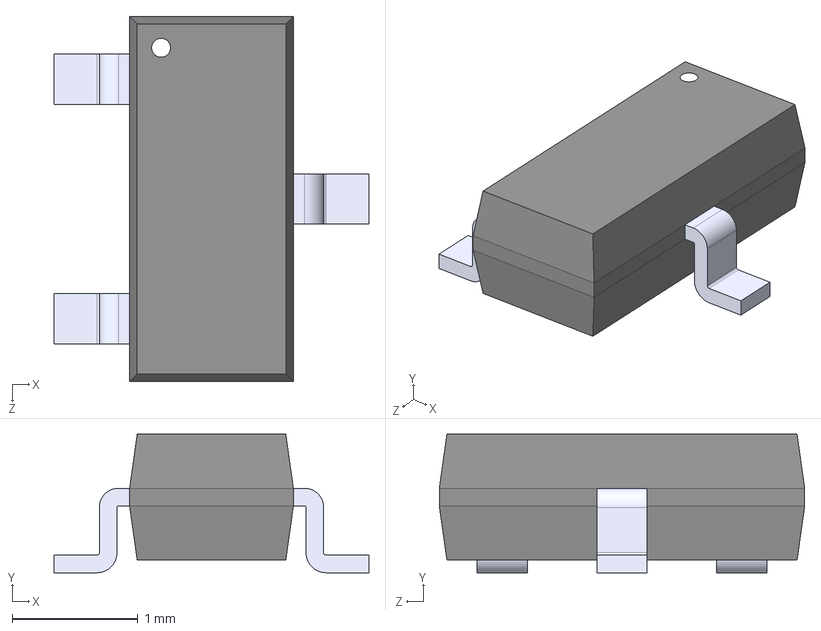
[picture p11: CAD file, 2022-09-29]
PCB/LibComponent/3Dmodel/BSS138.STEP
2.50 x 1.10 x 2.90 mm

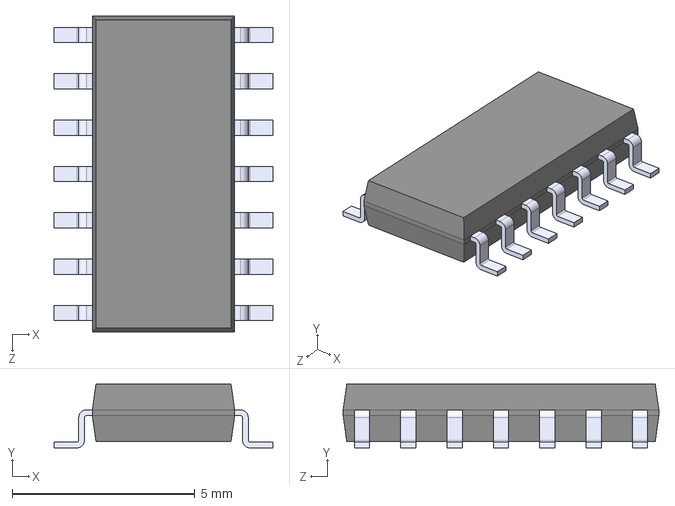
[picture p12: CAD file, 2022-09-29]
PCB/LibComponent/3Dmodel/TXB0104D.STEP
6.00 x 1.75 x 8.65 mm

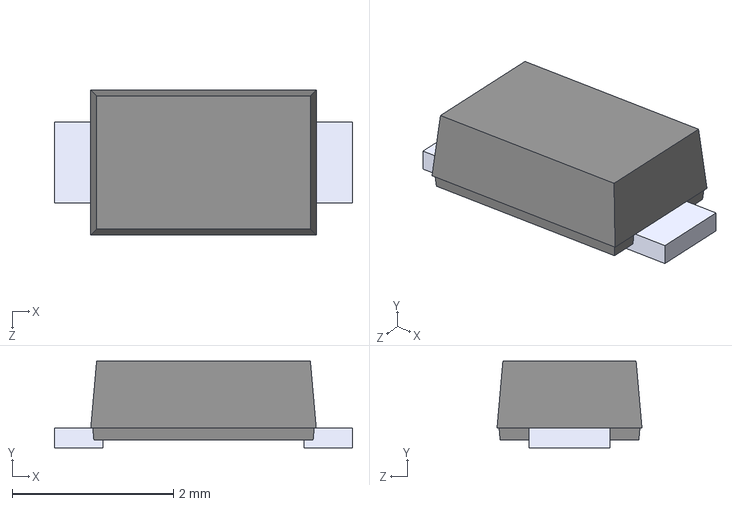
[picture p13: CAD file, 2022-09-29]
PCB/LibComponent/3Dmodel/S07M-GS18.STEP
3.70 x 1.08 x 1.80 mm

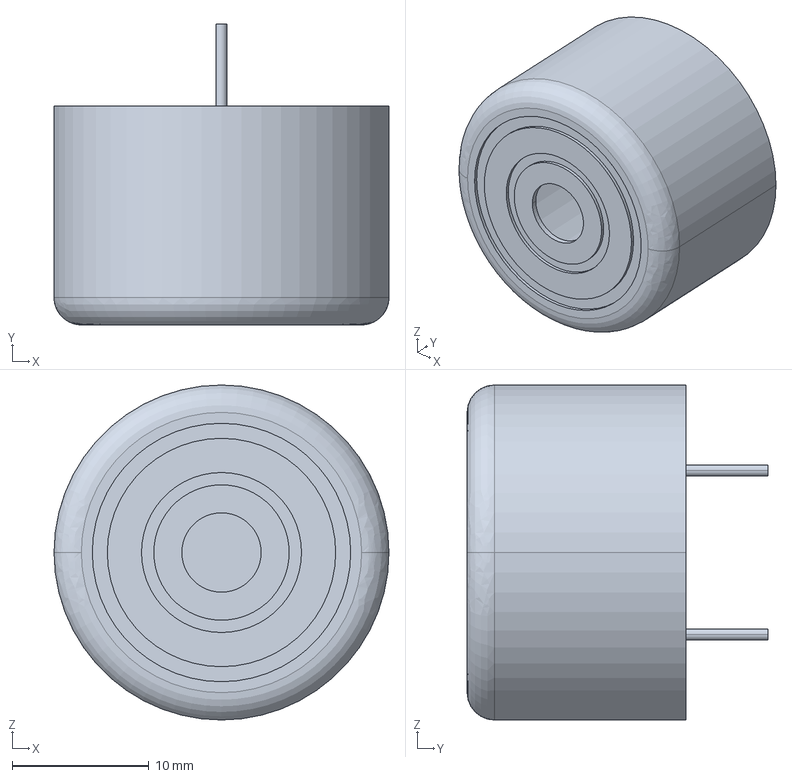
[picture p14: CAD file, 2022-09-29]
PCB/LibComponent/3Dmodel/KPEG203.STEP
24.5 x 22.0 x 24.5 mm

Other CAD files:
PCB/LibComponent/3Dmodel/TC1014-1.8VCT713.STEP
PCB/LibComponent/3Dmodel/PCA9306D_112.STEP
PCB/LibComponent/3Dmodel/5034800800.STEP
3DFiles/Blocage_Rotation_Canne/Blocage_Rotation_Canne.f3d
3DFiles/Boitier_CanneASon/Boitier_CanneASon.f3d
3DFiles/Support_Moteur_Vibrant/Support_Moteur_Vibrant.f3d

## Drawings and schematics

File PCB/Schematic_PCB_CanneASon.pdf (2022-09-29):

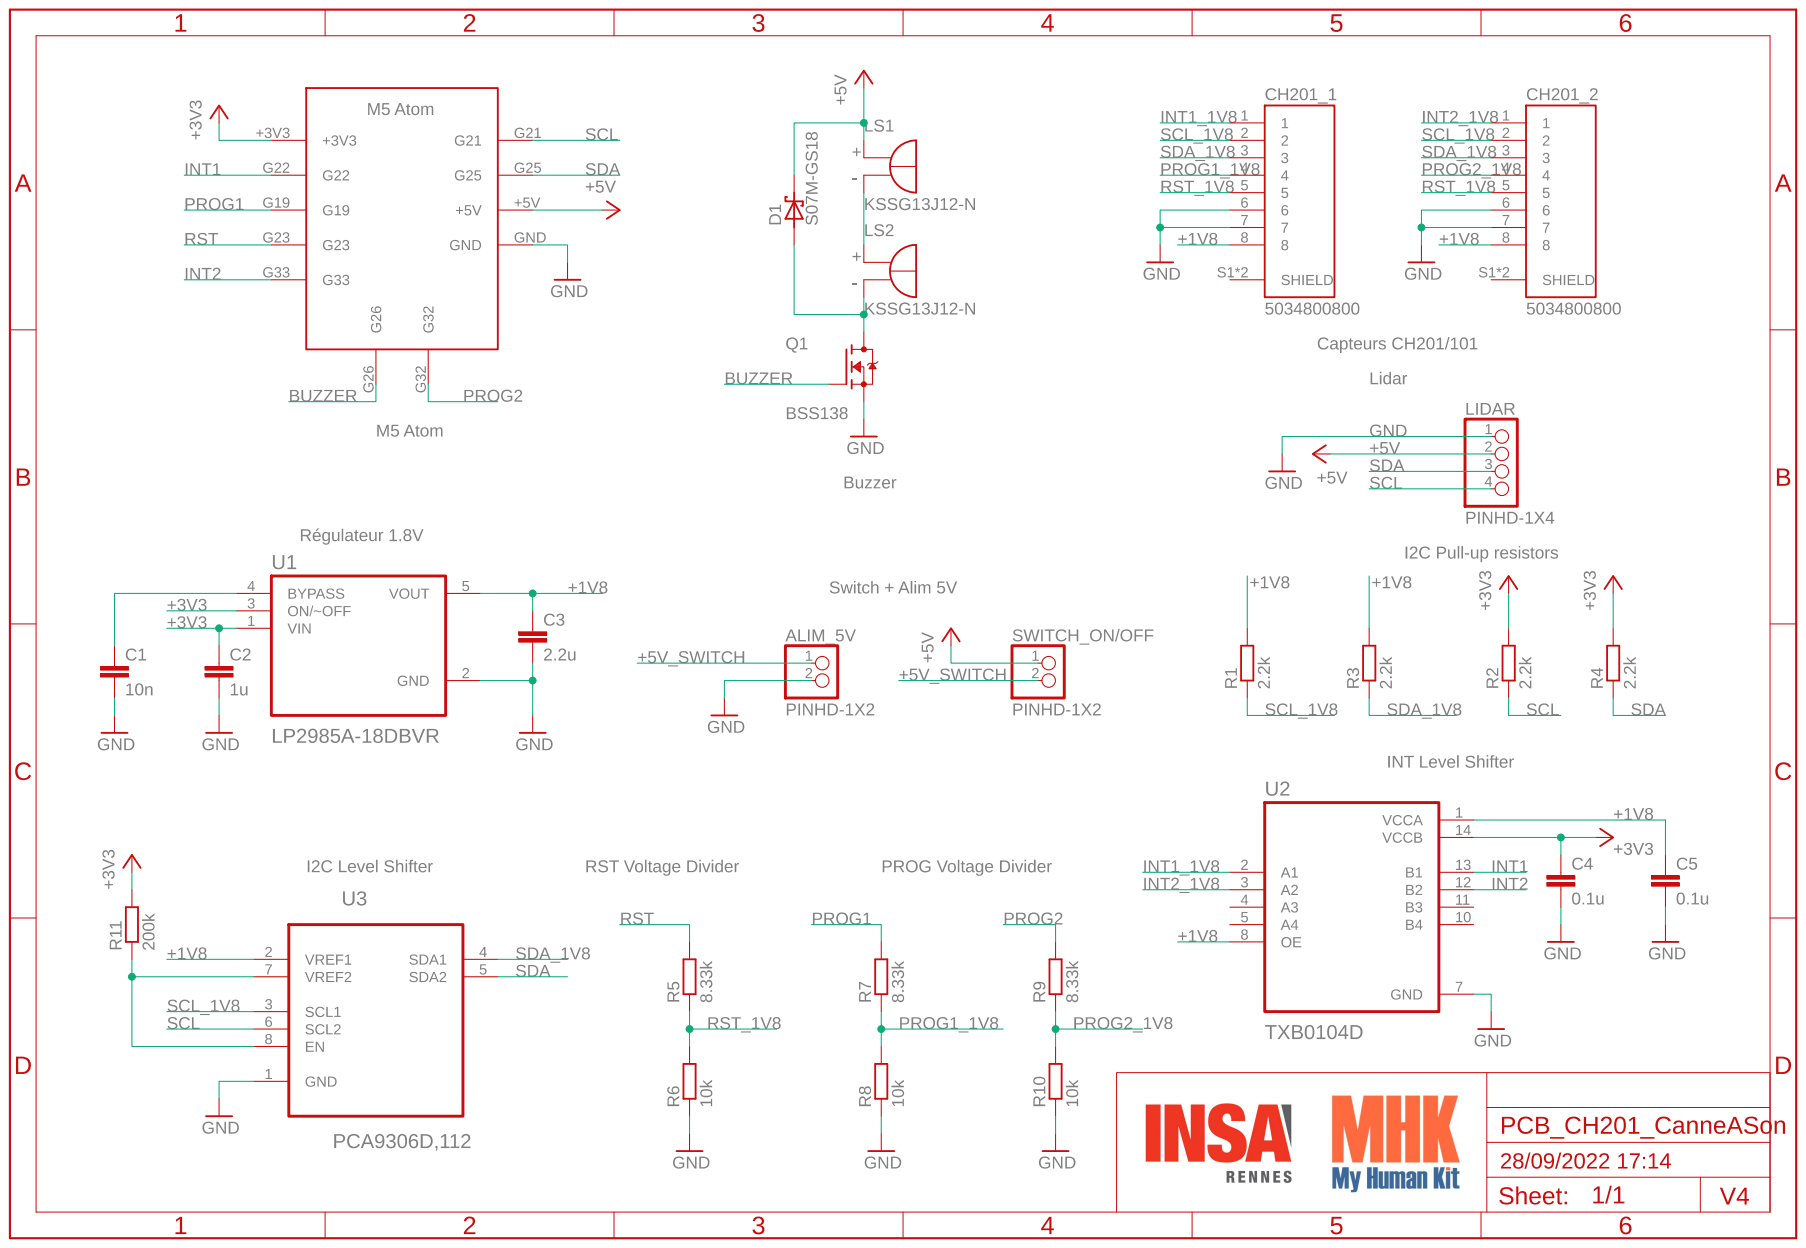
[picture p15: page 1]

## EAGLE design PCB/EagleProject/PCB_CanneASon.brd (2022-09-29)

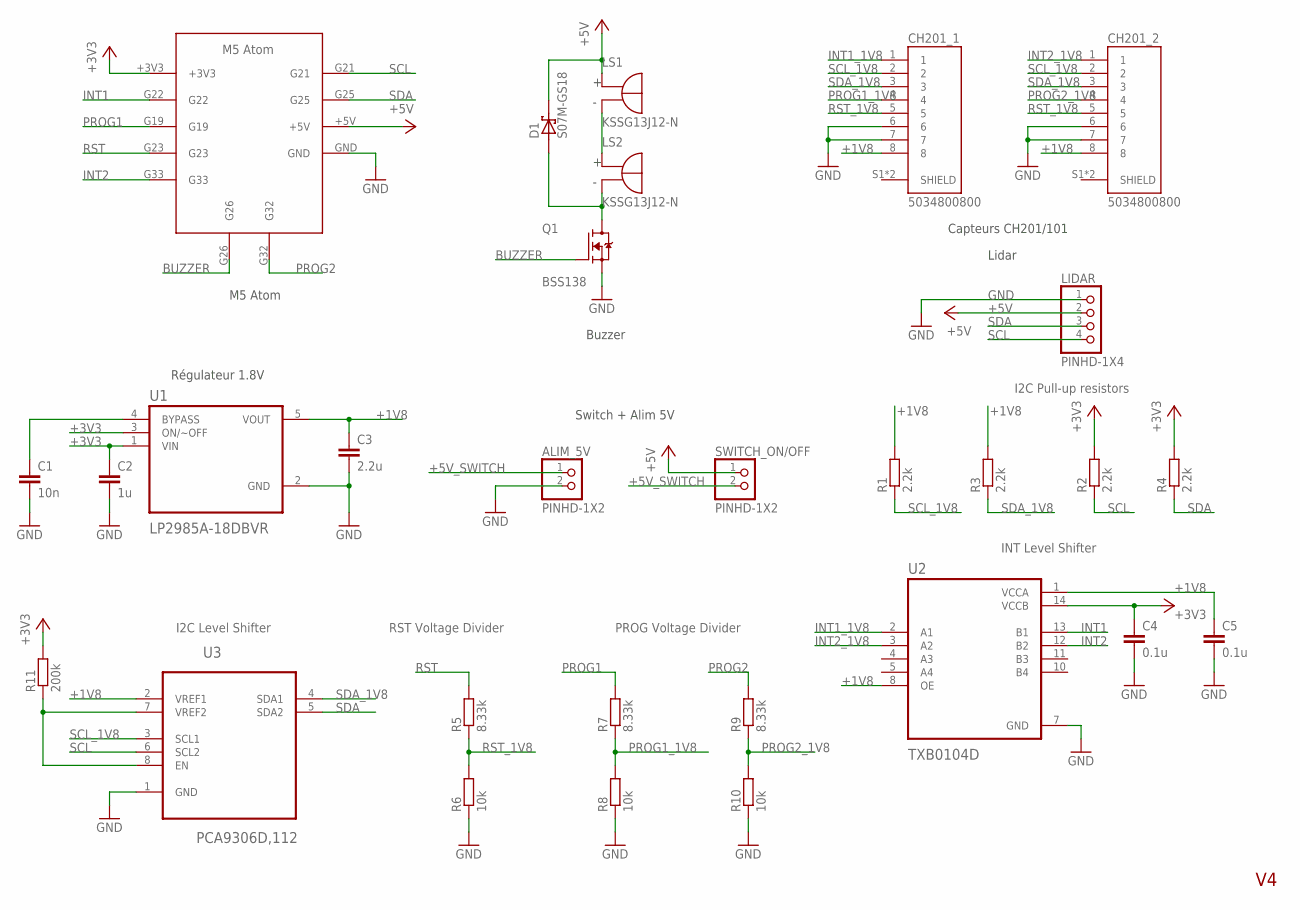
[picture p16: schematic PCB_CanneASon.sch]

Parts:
ALIM_5V: PINHD-1X2; 1X02
C1: 10n; C0805
C2: 1u; C0805
C3: 2.2u; C0805
C4, C5: 0.1u; C0805
CH201_1, CH201_2: 5034800800; MOLEX_5034800800
D1: S07M-GS18; DO-219AB
LIDAR: PINHD-1X4; 1X04
LS1, LS2: KSSG13J12-N; XDCR_KSSG13J12-N
Q1: BSS138; SOT95P240X111-3N
R1, R2, R3, R4: 2.2k; R0805
R5, R7, R9: 8.33k; R0805
R6, R8, R10: 10k; R0805
R11: 200k; R0805
SWITCH_ON/OFF: PINHD-1X2; 1X02
U1: LP2985A-18DBVR; SOT95P280X145-5N
U2: TXB0104D; SOIC127P600X175-14N
U3: PCA9306D,112; SOIC127P600X175-8N
U$1: M5ATOM

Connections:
+1V8: C3.1, C5.1, CH201_1.8, CH201_2.8, R1.2, R3.2, U1.5 (VOUT), U2.1 (VCCA), U2.8 (OE), U3.2 (VREF1)
+3V3: C2.1, C4.1, R2.2, R4.2, R11.2, U1.1 (VIN), U1.3 (ON/~OFF), U2.14 (VCCB), U$1.+3V3
+5V: D1.C, LIDAR.2, LS1.P (POS), SWITCH_ON/OFF.1, U$1.+5V
+5V_SWITCH: ALIM_5V.1, SWITCH_ON/OFF.2
BUZZER: Q1.1 (G), U$1.G26
GND: ALIM_5V.2, C1.2, C2.2, C3.2, C4.2, C5.2, CH201_1.6, CH201_1.7, CH201_2.6, CH201_2.7, LIDAR.1, Q1.2 (S), R6.1, R8.1, R10.1, U1.2 (GND), U2.7 (GND), U3.1 (GND), U$1.GND
INT1: U2.13 (B1), U$1.G22
INT1_1V8: CH201_1.1, U2.2 (A1)
INT2: U2.12 (B2), U$1.G33
INT2_1V8: CH201_2.1, U2.3 (A2)
unnamed: C1.1, U1.4 (BYPASS)
unnamed: LS1.N (NEG), LS2.P (POS)
unnamed: D1.A, LS2.N (NEG), Q1.3 (D)
unnamed: R11.1, U3.7 (VREF2), U3.8 (EN)
PROG1: R7.2, U$1.G19
PROG1_1V8: CH201_1.4, R7.1, R8.2
PROG2: R9.2, U$1.G32
PROG2_1V8: CH201_2.4, R9.1, R10.2
RST: R5.2, U$1.G23
RST_1V8: CH201_1.5, CH201_2.5, R5.1, R6.2
SCL: LIDAR.4, R2.1, U3.6 (SCL2), U$1.G21
SCL_1V8: CH201_1.2, CH201_2.2, R1.1, U3.3 (SCL1)
SDA: LIDAR.3, R4.1, U3.5 (SDA2), U$1.G25
SDA_1V8: CH201_1.3, CH201_2.3, R3.1, U3.4 (SDA1)

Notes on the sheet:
Buzzer
Switch + Alim 5V
Lidar
Capteurs CH201/101
M5 Atom
Régulateur 1.8V
I2C Level Shifter
INT Level Shifter
PROG Voltage Divider
I2C Pull-up resistors
RST Voltage Divider

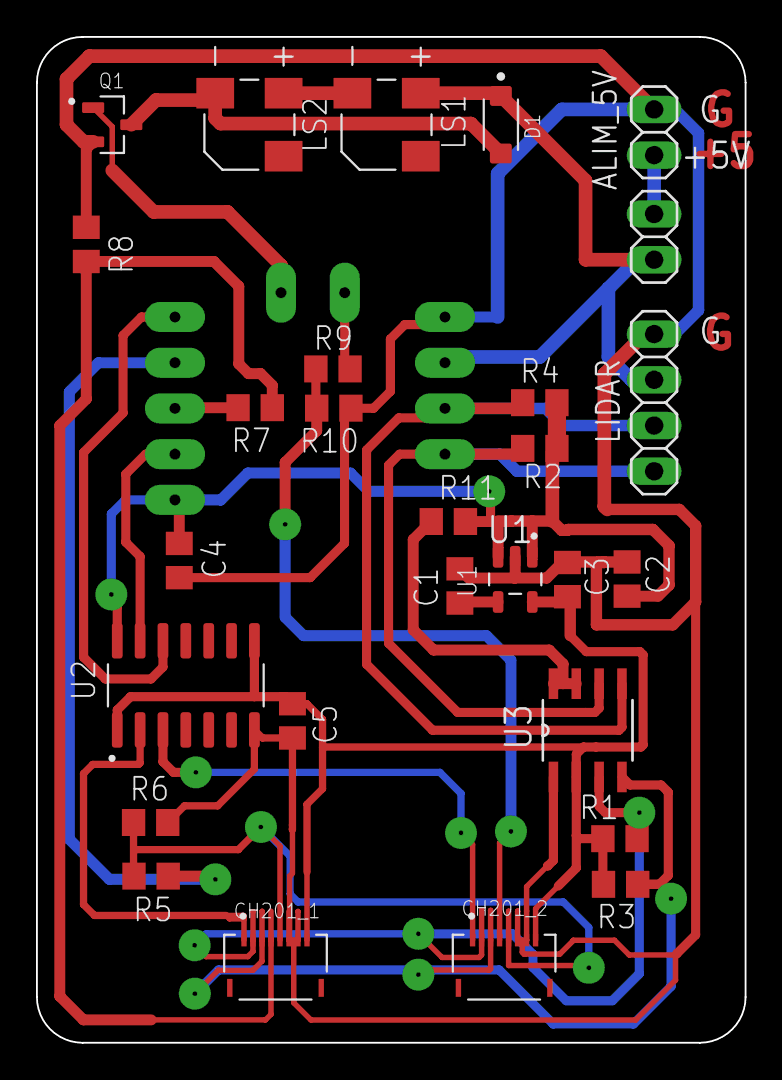
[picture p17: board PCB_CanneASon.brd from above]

Board: 2 copper layers, 39.4 x 55.9 mm, 29 parts (0 on the bottom side), 24 nets.

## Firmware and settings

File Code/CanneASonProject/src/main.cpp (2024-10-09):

#include <Arduino.h>
#include "TFMiniPlus.h"
#include "boardConfig.h"
#include "CH201.h"
#include "MPU6050_custom.h"
#include "sound.h"


/*
 *  Constructors call
 */
MPU6050_custom IMU;
sound son;


/*
 *  Global variables
 */
unsigned int distance_measured[NB_CH201_SENSOR+1];
unsigned int distance_old_data[NB_CH201_SENSOR+1];
unsigned int amplitude[NB_CH201_SENSOR+1];
unsigned int distance_derivative;
bool buz_active[NB_BIP] = {0,0,0,0};
float pitch, roll;
unsigned long timeBuz;


/*
 *  Function prototype
 */
void measurementProcessing();


void setup() {
    Wire.begin(PIN_SDA, PIN_SCL, 100000UL);
    Serial.begin(9600);
    delay(400);

    if(TFMP.begin(1000) != true){   // Configuration du lidar
         while(1){}
    }
    
    if(initCH201() != true){        // Configuration des capteurs ultrasons CH201
        while(1){}
    }

    IMU.Init();

    delay(100);

    son.soundSystemReady();
}

void loop() {
    if(sendReceiveCH201(distance_measured,amplitude) == 2){ // Appel de la fonction permettant de demander au capteur CH201 une mesure et permettant la lecture de cette mesure
        measurementProcessing();                            // Si la lecture de la mesure a été effectué (valeur retournée = 2), appel de la fonction de traitement
    }
}


void measurementProcessing() {
    IMU.getAttitude(&pitch, &roll);    // Lecture des valeurs provenant de la centrale inertielle

    if(pitch > -70 && pitch < -10) {   // Contrôle de la bonne position de la canne pour qu'elle ne fasse pas de bips quand elle est tenue verticalement ou posée sur une table
        /*  Acquisition lidar   */
        distance_old_data[0] = distance_measured[0];    // Stockage de la valeur précédente mesurée par le lidar
        distance_measured[0] = TFMP.getDistance();      // Mesure de la valeur par le lidar

        distance_derivative = (distance_measured[0] - distance_old_data[0]) * 1/(100*CH201_MEASUREMENT_INTERVAL);    // Calcul de la vitesse de rapprochement d'un obstacle (dérivée du signal)
        if ((/*distance_derivative < -5 ||*/ distance_measured[0] < 160) && distance_measured[0] > 30 && buz_active[0] == 0) {  // Si un obstacle proche est détecté (via dérivée ou mesure directe)
            buz_active[0] = 1;
        } else if (distance_measured[0] > 400 && buz_active[0] == 0) {  // Si une longue distance est détectée via le lidar (escalier ou trou dans le sol)
            buz_active[3] = 1;
        } else if ((distance_derivative > 5 || distance_measured[0] > 170) && distance_measured[0] > 120) { // Si il n'y a plus d'obstacles détectés (via dérivée ou mesure directe)
            buz_active[0] = 0;
            buz_active[3] = 0;
        }

        /*  Acquisition capteur ultrason droit  */
        if (distance_measured[1] < 1900 && amplitude[1] > 10000 && buz_active[1] == 0) {    // Si un obstacle proche est détecté (via mesure directe et vérification de l'amplitude du signal)
            buz_active[1] = 1;
        } else if (distance_measured[1] > 1900 || amplitude[1] < 2000) {    // Si il n'y a plus d'obstacles détectés (via mesure directe ou mesure de l'amplitude du signal)
            buz_active[1] = 0;
        }

        /*  Acquisition capteur ultrason haut  */
        if(distance_measured[2] < 1500 && distance_measured[2] > 300 && amplitude[2] > 5000 && buz_active[2] == 0){     // Si un obstacle haut est détecté (via mesure directe et vérification de l'amplitude du signal)
            buz_active[2] = 1;
            timeBuz = millis();
        } else  if ((distance_measured[2] > 1500 || amplitude[2] < 2000) && (millis() - timeBuz > 400)){    // Si il n'y a plus d'obstacles haut détectés (via mesure directe ou mesure de l'amplitude du signal)
            buz_active[2] = 0;
        }

        son.makeSound(buz_active);        
    }
}

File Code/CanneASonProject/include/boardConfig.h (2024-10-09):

/*
 *  Fichier permettant la configuration de la canne
 */

#ifndef PCB_CANNEASON_BOARDCONFIG_H
#define PCB_CANNEASON_BOARDCONFIG_H

/*  Définition de la fréquence du microcontrôleur  */
#define UC_FREQUENCY        100000UL

/*  Paramétrage des capteurs ultrasons CH201  */
#define NB_CH201_SENSOR     2                           // Choix du nombre de capteurs utilisés
#define CH201_FIRMWARE      ch201_gprmt_init            // Firmware des capteurs (ici le mode Multi Thresholds)
#define CH201_MODE          CH_MODE_TRIGGERED_TX_RX     // Mode de capture (CH_MODE_FREERUN ou CH_MODE_TRIGGERED_TX_RX)
#define CH201_MAX_RANGE     4000                        // Distance mesurable maximum en mm
#define CH201_MEASUREMENT_INTERVAL	100	                // Période d'échantillonnage, en ms. Période de 100ms = fréquence d'échantillonnage de 10Hz

/*  Déclaration des Entrées/Sorties  */
#define BUZZER_PIN          0           
#define PIN_RESET           2
#define PIN_SDA             6
#define PIN_SCL             7
#define INT1                4
#define INT2                1
#define PROG1               3
#define PROG2               8
#define VIBREUR_PIN        10
#define switchBuzVibreur1                20
#define switchBuzVibreur2                21 

/*  Paramétrage du retour à l'utiliateur via le buzzer  */
#define NB_BIP              4       // Nombre de cas différents à traiter (ici 4)
#define VOLUME_BIP          127     // Volume des bips
#define BIP_OBSTACLE        2500    // Fréquence bip en cas d'obstacle en Hz
#define BIP_ESCALIER        5000    // Fréquence bip en cas d'escalier/trou en Hz
#define BIP_OBSTACLE_HAUTEUR 800    // Fréquence bip en cas d'obstacle en hauteur en Hz

extern hw_timer_t *My_timer;
#endif //PCB_CANNEASON_BOARDCONFIG_H

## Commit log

2022-09-29 Add 3D Files
    [Boitier_CanneASon.f3d, CanneASon_Part1.stl, CanneASon_Part2.stl]
2022-09-29 Add PCB Files
    * EAGLE project to make change to the PCB
    * Gerber + Drill files to order the PCB
    * Schematic
    [5034800800.STEP, BSS138.STEP, KPEG203.STEP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]
2022-10-18 Fix high obstacles detection
    [main.cpp]
2023-11-07 add start-up delay for sensor initialisation
2024-10-09 Nouvelle version : Canne à Son V2.1
    [AdaptateurBoitier_V2.0_to_V2.1.stl, Blocage_Rotation_Canne.f3d, Blocage_Rotation_Part1.stl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]
